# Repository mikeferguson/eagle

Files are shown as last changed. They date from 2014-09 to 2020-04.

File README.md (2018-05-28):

## Eagle CAD Stuff

This is a collection of libraries and board designs using Eagle CAD.

## Installing Eagle 7.1 (on Ubuntu 18.04)

    sudo apt-get install gcc-multilib
    sudo apt-get install libxrender1:i386 libxrandr2:i386 libxcursor1:i386 libfreetype6:i386 libfontconfig1:i386 libxi6:i386 libstdc++6:i386 libjpeg62:i386 libssl1.0.0:i386

    wget http://web.cadsoft.de/ftp/eagle/program/7.1/eagle-lin-7.1.0.run
    chmod a+x eagle-lin-7.1.0.run
    ./eagle-lin-7.1.0.run /opt

## Adding Launcher on Ubuntu 18.04
Add a file called eagle.desktop to ~/.local/share/applications:

    #!/usr/bin/env xdg-open
    [Desktop Entry]
    Comment[en_US]=Eagle 7.1
    Terminal=false
    Name[en_US]=Eagle
    Exec=/opt/eagle-7.1.0/bin/eagle
    Type=Application
    Icon=/opt/eagle-7.1.0/bin/eagleicon50.png
    StartupWMClass=dont_care

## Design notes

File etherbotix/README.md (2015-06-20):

# Etherbotix

## Notes

Notes from stuffing Rev. A:
 * DC-DC regulator is too close to Dynamixel headers (has to be installed slightly angled away)
 * X2 footprint is missing direction indicator.
 * X2 footprint should be a bit wider for hand-stuffing.
 * C39, C40 are 22pF (might still be too high)
 * Encoder capacitor values may not be right (too aggressive of a filter)

Need to source 7/16" or 11mm length, 4-40 or M3 standoff (possibly 952-1520-ND)

## Revision History

 * Rev. B - (Forthcoming)
   * Increase size of P1 indicator on X2.
   * Moved ethernet parts away from MD-03 mounting hole
   * TODO: move U3 away from AX headers
   * TODO: move J1 (ethernet jack) up a bit to avoid collision with IMU
   * TODO: update values of C39, C40
   * TODO: update values of C4, C13, C17, C18
   * TODO: move R19, R24, R25 out from under IMU
   * Move M1 encoder filter away from MD-03 mounting hole
   * Add testpads for PE0, PE1, PE4, PA8
   * Add testpads to encoders, clocks, and current sense
   * Add jumper to force bootloader
   * TODO: change away from clikmate connector
 * Rev. A - September 7, 2014
   * First release

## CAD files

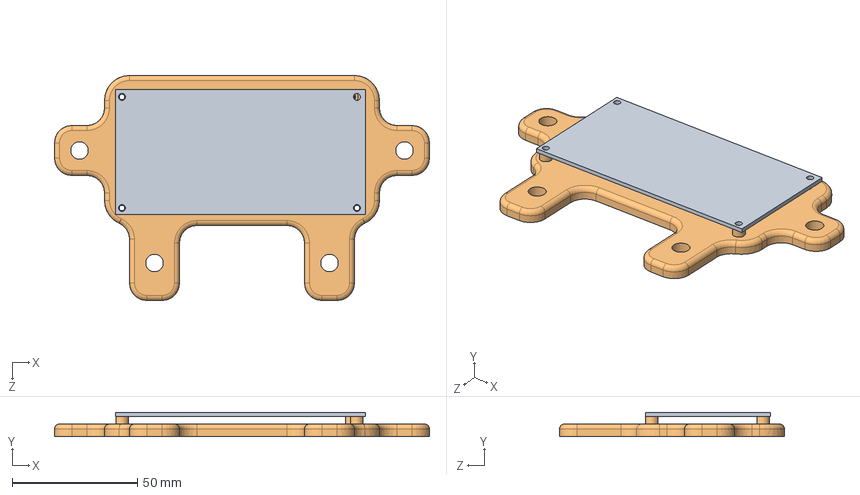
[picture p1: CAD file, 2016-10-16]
etherbotix/board-mounts/stackup.SLDASM
150.0 x 9.60 x 90.0 mm
brd-basic
mount

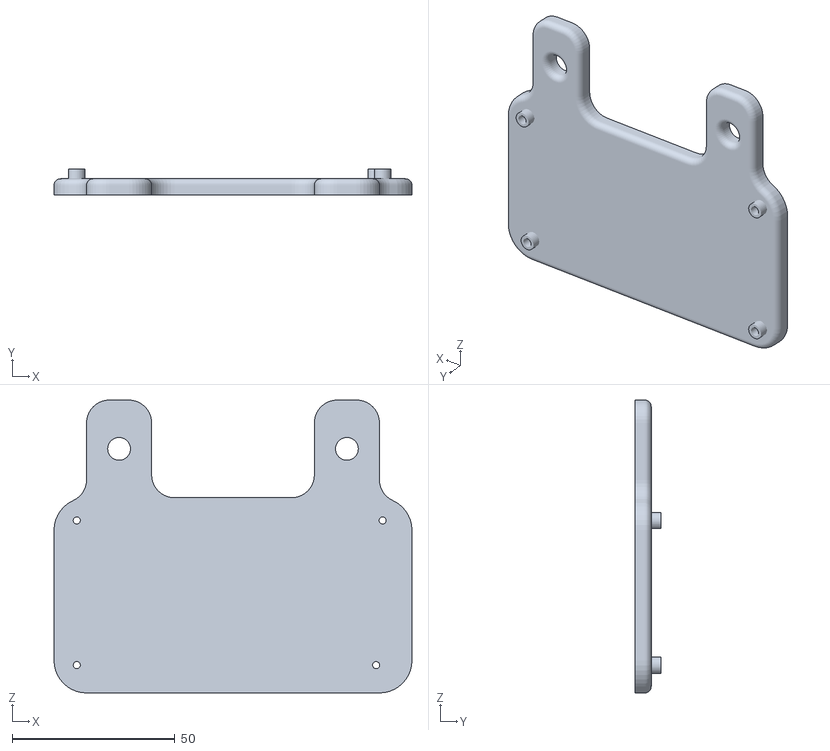
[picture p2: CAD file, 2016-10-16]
etherbotix/board-mounts/mount-teeth.STL
110.0 x 8.00 x 90.0

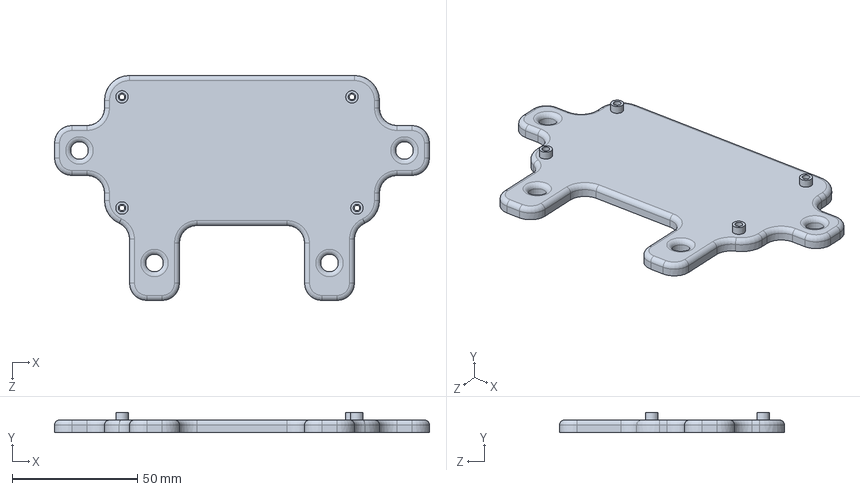
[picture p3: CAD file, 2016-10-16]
etherbotix/board-mounts/mount.SLDPRT
150.0 x 8.00 x 90.0 mm

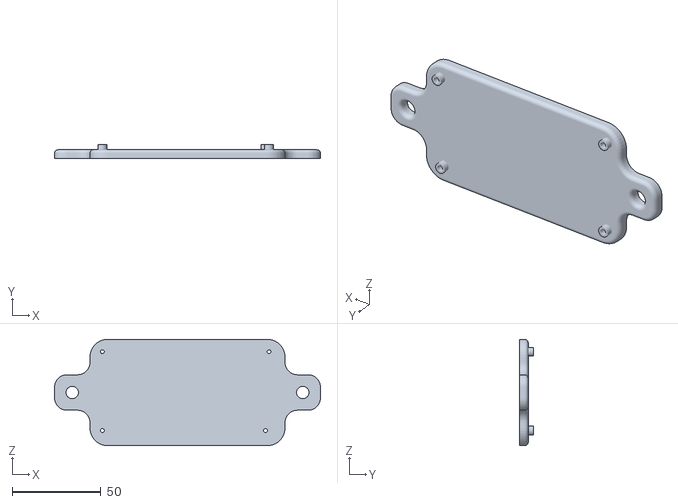
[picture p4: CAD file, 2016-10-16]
etherbotix/board-mounts/mount-end-mounts.STL
150.0 x 8.00 x 60.0

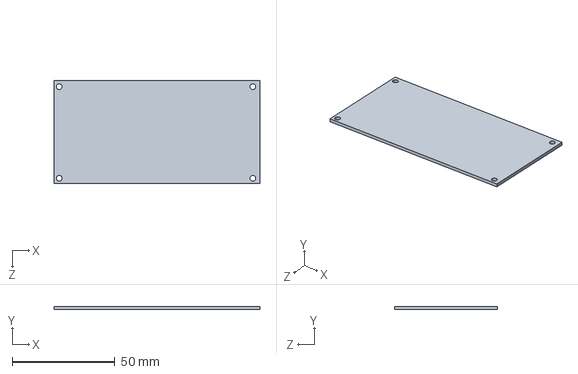
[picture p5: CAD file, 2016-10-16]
etherbotix/board-mounts/brd-basic.SLDPRT
100.0 x 1.60 x 50.0 mm

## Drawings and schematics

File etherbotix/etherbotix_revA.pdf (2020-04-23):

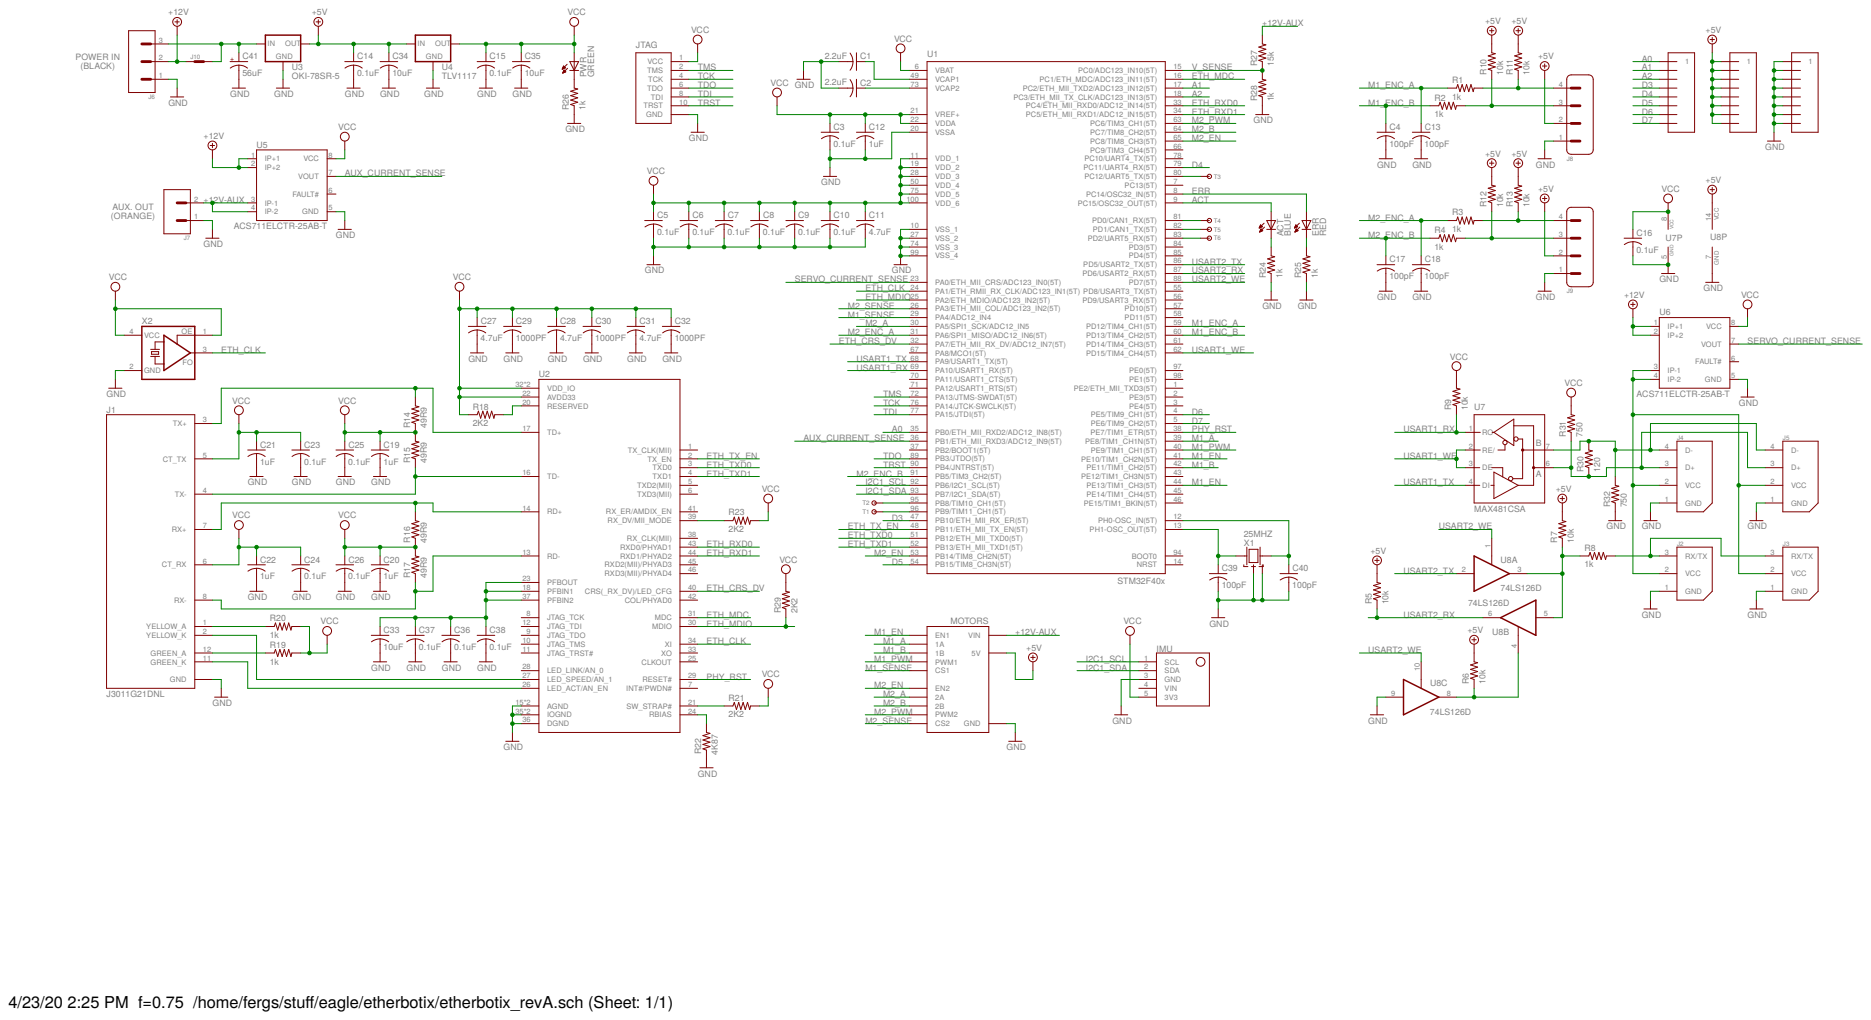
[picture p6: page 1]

100 | ACT

4/23/20 2:25 PM f=0.75 /home/fergs/stuff/eagle/etherbotix/etherbotix_revA.sch (Sheet: 1/1)

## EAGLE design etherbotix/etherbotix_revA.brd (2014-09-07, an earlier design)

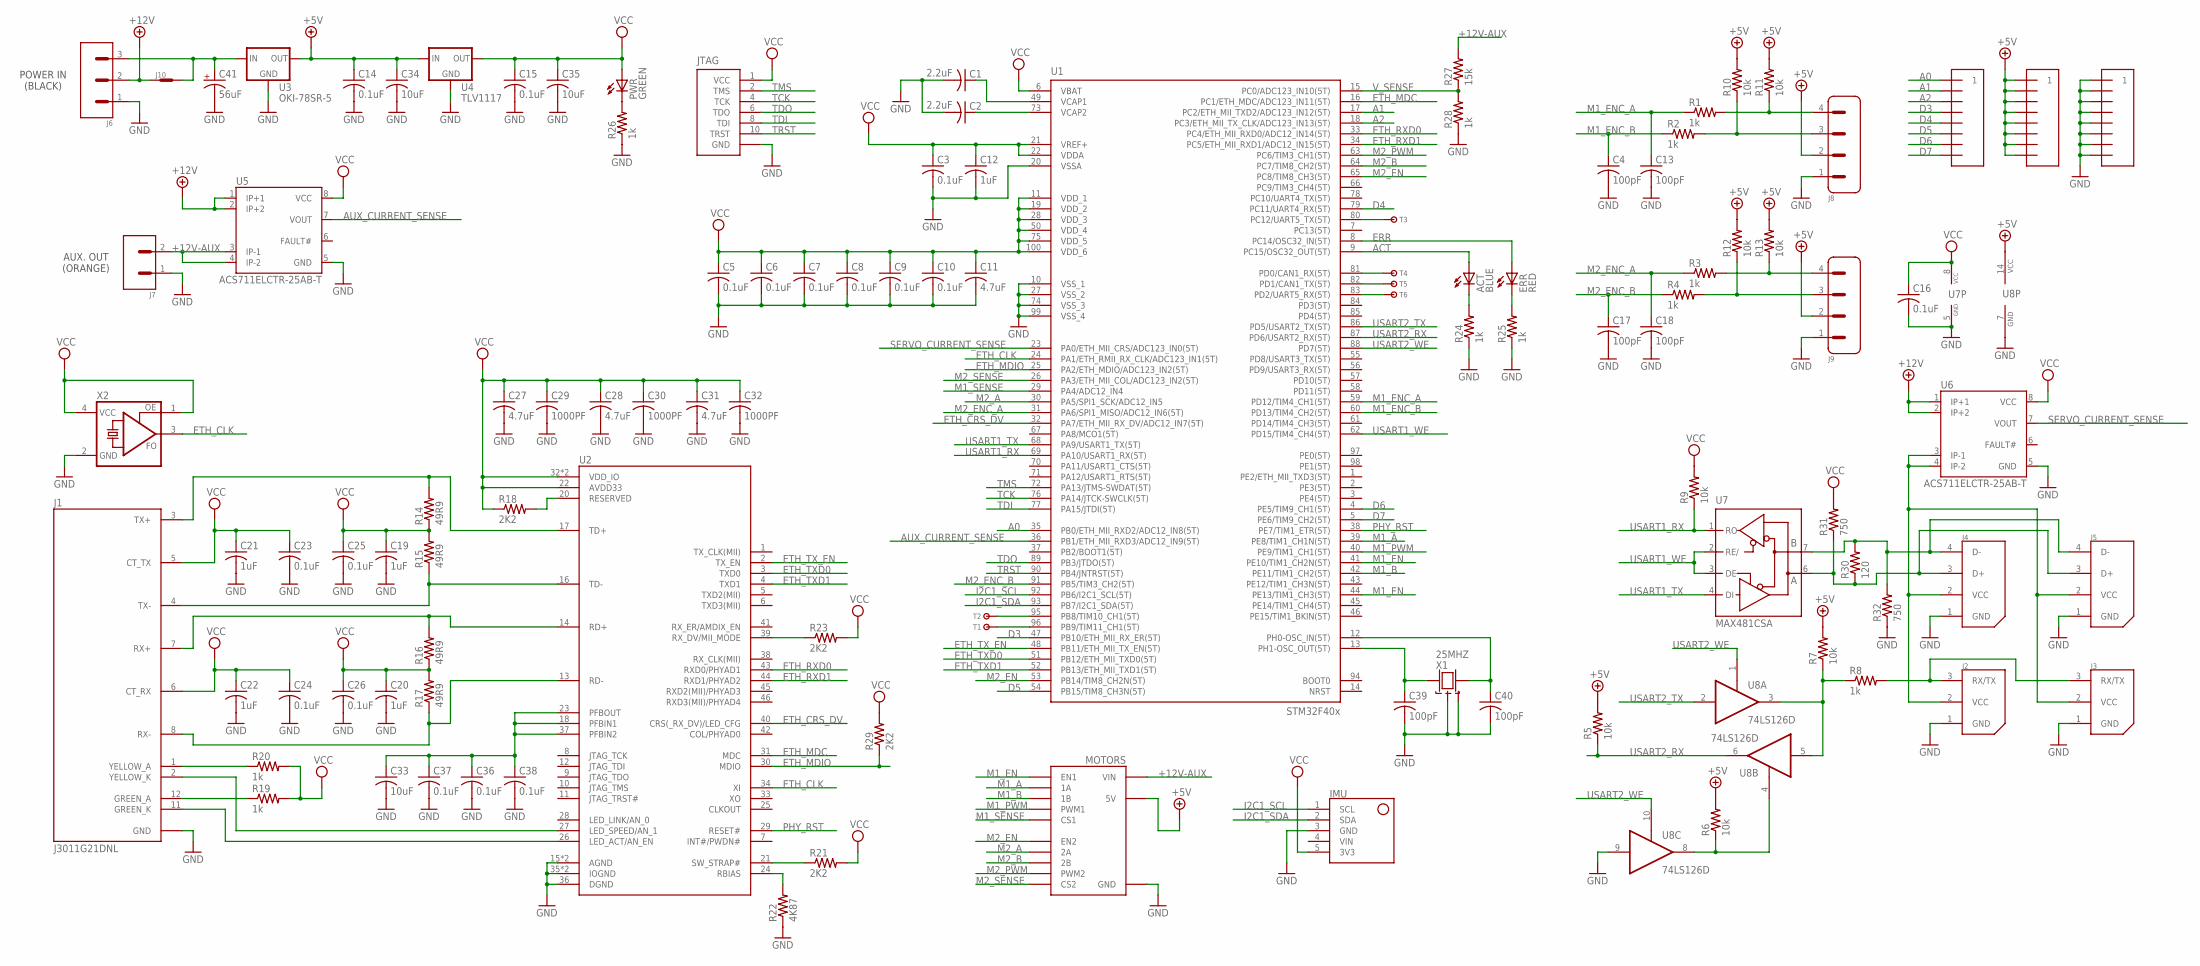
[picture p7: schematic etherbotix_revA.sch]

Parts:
ACT: BLUE; LED0603
C1, C2: 2.2uF; C0603
C3, C5, C6, C7, C8, C9, C10, C14, C15, C16, C23, C24, C25, C26, C36, C37, C38: 0.1uF; C0603
C4, C13, C17, C18, C39, C40: 100pF; C0603
C11, C27, C28, C31: 4.7uF; 0603
C12, C19, C20, C21, C22: 1uF; C0603
C29, C30, C32: 1000PF; 0603
C33, C34, C35: 10uF; C0603
C41: 56uF; OSCON_SVPF_6.3MM
ERR: RED; LED0603
IMU: MINI9IMU
J1: J3011G21DNL; J3
J2, J3: 22-03-5035; 5267-3
J4, J5: 22-03-5045; 5267-4
J6: 1760520000
J7: 1760490000
J8, J9: 502443-0470
J10: JUMPER; J2
JTAG: CORTEX_DEBUG-SHROUDED; 3220-10-0300-00
MOTORS: MD03A
PWR: GREEN; LED0603
R1, R2, R3, R4, R8, R19, R20, R24, R25, R26, R28: 1k; 0603
R5, R6, R7, R9, R10, R11, R12, R13: 10k; 0603
R14, R15, R16, R17: 49R9; 0603
R18, R21, R23, R29: 2K2; 0603
R22: 4K87; 0603
R27: 15k; 0603
R30: 120; 0603
R31, R32: 750; 0603
T1, T2, T3, T4, T5, T6: TESTPAD; TEST
U1: STM32F407V; TQFP100
U2: TLK110; LQFP48
U3: OKI-78SR-5; OKI-78SR
U4: TLV1117; DPAK
U5, U6: ACS711ELCTR-25AB-T; SOIC8
U7: MAX481CSA; SO08
U8: 74LS126D; SO14
U$1, U$2, U$3: HEADER8; 1X8
X1: 25MHZ; 4LCC
X2: ASEMB-50.000MHZ-XY-T; OSCILLATOR

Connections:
+5V: C14.1, C34.1, J8.2, J9.2, MOTORS.5V, R5.2, R6.2, R7.2, R10.2, R11.2, R12.2, R13.2, U3.P$3 (OUT), U4.3 (IN), U8.14 (VCC), U$2.P$1 (1), U$2.P$2, U$2.P$3, U$2.P$4, U$2.P$5, U$2.P$6, U$2.P$7, U$2.P$8
+12V: J6.2, J10.A, U5.1 (IP+1), U5.2 (IP+2), U6.1 (IP+1), U6.2 (IP+2)
+12V-AUX: J7.2, MOTORS.VIN1 (VIN), MOTORS.VIN2 (VIN), R27.2, U5.3 (IP-1), U5.4 (IP-2)
A0: U1.35 (PB0/ETH_MII_RXD2/ADC12_IN8(5T)), U$1.P$1 (1)
A1: U1.17 (PC2/ETH_MII_TXD2/ADC123_IN12(5T)), U$1.P$2
A2: U1.18 (PC3/ETH_MII_TX_CLK/ADC123_IN13(5T)), U$1.P$3
ACT: ACT.A, U1.9 (PC15/OSC32_OUT(5T))
AUX_CURRENT_SENSE: U1.36 (PB1/ETH_MII_RXD3/ADC12_IN9(5T)), U5.7 (VOUT)
D3: U1.47 (PB10/ETH_MII_RX_ER(5T)), U$1.P$4
D4: U1.79 (PC11/UART4_RX(5T)), U$1.P$5
D5: U1.54 (PB15/TIM8_CH3N(5T)), U$1.P$6
D6: U1.4 (PE5/TIM9_CH1(5T)), U$1.P$7
D7: U1.5 (PE6/TIM9_CH2(5T)), U$1.P$8
ERR: ERR.A, U1.8 (PC14/OSC32_IN(5T))
ETH_CLK: U1.24 (PA1/ETH_RMII_RX_CLK/ADC123_IN1(5T)), U2.34 (XI), X2.3 (FO)
ETH_CRS_DV: U1.32 (PA7/ETH_MII_RX_DV/ADC12_IN7(5T)), U2.40 (CRS(_RX_DV)/LED_CFG)
ETH_MDC: U1.16 (PC1/ETH_MDC/ADC123_IN11(5T)), U2.31 (MDC)
ETH_MDIO: R29.1, U1.25 (PA2/ETH_MDIO/ADC123_IN2(5T)), U2.30 (MDIO)
ETH_RXD0: U1.33 (PC4/ETH_MII_RXD0/ADC12_IN14(5T)), U2.43 (RXD0/PHYAD1)
ETH_RXD1: U1.34 (PC5/ETH_MII_RXD1/ADC12_IN15(5T)), U2.44 (RXD1/PHYAD2)
ETH_TXD0: U1.51 (PB12/ETH_MII_TXD0(5T)), U2.3 (TXD0)
ETH_TXD1: U1.52 (PB13/ETH_MII_TXD1(5T)), U2.4 (TXD1)
ETH_TX_EN: U1.48 (PB11/ETH_MII_TX_EN(5T)), U2.2 (TX_EN)
GND: C1.2, C2.2, C3.2, C4.2, C5.2, C6.2, C7.2, C8.2, C9.2, C10.2, C11.2, C12.2, C13.2, C14.2, C15.2, C16.2, C17.2, C18.2, C19.2, C20.2, C21.2, C22.2, C23.2, C24.2, C25.2, C26.2, C27.2, C28.2, C29.2, C30.2, C31.2, C32.2, C33.2, C34.2, C35.2, C36.2, C37.2, C38.2, C39.2, C40.2, C41.-, IMU.3 (GND), J1.9 (GND), J1.10 (GND), J1.A (GND), J1.B (GND), J2.1 (GND), J3.1 (GND), J4.1 (GND), J5.1 (GND), J6.1, J7.1, J8.1, J9.1, JTAG.3 (GND), JTAG.5 (GND), JTAG.9 (GND), MOTORS.GND1 (GND), MOTORS.GND2 (GND), R22.1, R24.1, R25.1, R26.1, R28.1, R32.1, U1.10 (VSS_1), U1.20 (VSSA), U1.27 (VSS_2), U1.74 (VSS_3), U1.99 (VSS_4), U2.15 (AGND), U2.19 (AGND), U2.35 (IOGND), U2.36 (DGND), U2.47 (IOGND), U3.P$2 (GND), U4.1 (GND), U5.5 (GND), U6.5 (GND), U7.5 (GND), U8.7 (GND), U8.9 (I), U$3.P$1 (1), U$3.P$2, U$3.P$3, U$3.P$4, U$3.P$5, U$3.P$6, U$3.P$7, U$3.P$8, X1.2 (G1), X1.4 (G2), X2.2 (GND)
I2C1_SCL: IMU.1 (SCL), U1.92 (PB6/I2C1_SCL(5T))
I2C1_SDA: IMU.2 (SDA), U1.93 (PB7/I2C1_SDA(5T))
M1_A: MOTORS.1A, U1.39 (PE8/TIM1_CH1N(5T))
M1_B: MOTORS.1B, U1.42 (PE11/TIM1_CH2(5T))
M1_EN: MOTORS.EN1, U1.41 (PE10/TIM1_CH2N(5T)), U1.44 (PE13/TIM1_CH3(5T))
M1_ENC_A: C13.1, R1.1, U1.59 (PD12/TIM4_CH1(5T))
M1_ENC_B: C4.1, R2.1, U1.60 (PD13/TIM4_CH2(5T))
M1_PWM: MOTORS.PWM1, U1.40 (PE9/TIM1_CH1(5T))
M1_SENSE: MOTORS.CS1, U1.29 (PA4/ADC12_IN4)
M2_A: MOTORS.2A, U1.30 (PA5/SPI1_SCK/ADC12_IN5)
M2_B: MOTORS.2B, U1.64 (PC7/TIM8_CH2(5T))
M2_EN: MOTORS.EN2, U1.53 (PB14/TIM8_CH2N(5T)), U1.65 (PC8/TIM8_CH3(5T))
M2_ENC_A: C18.1, R3.1, U1.31 (PA6/SPI1_MISO/ADC12_IN6(5T))
M2_ENC_B: C17.1, R4.1, U1.91 (PB5/TIM3_CH2(5T))
M2_PWM: MOTORS.PWM2, U1.63 (PC6/TIM3_CH1(5T))
M2_SENSE: MOTORS.CS2, U1.26 (PA3/ETH_MII_COL/ADC123_IN2(5T))
unnamed: J1.4 (TX-), R15.1, U2.16 (TD-)
unnamed: J2.2 (VCC), J3.2 (VCC), J4.2 (VCC), J5.2 (VCC), U6.3 (IP-1), U6.4 (IP-2)
unnamed: C39.1, U1.13 (PH1-OSC_OUT(5T)), X1.1
unnamed: C1.1, U1.49 (VCAP1)
unnamed: C2.1, U1.73 (VCAP2)
unnamed: J8.3, R2.2, R10.1
unnamed: J8.4, R1.2, R11.1
unnamed: J9.4, R3.2, R13.1
unnamed: J9.3, R4.2, R12.1
unnamed: J4.3 (D+), J5.3 (D+), R30.1, R31.1, U7.6 (A)
unnamed: J4.4 (D-), J5.4 (D-), R30.2, R32.2, U7.7 (B)
unnamed: R7.1, R8.1, U8.3 (O), U8.5 (I)
unnamed: R6.1, U8.4 (OE), U8.8 (O)
unnamed: J2.3 (RX/TX), J3.3 (RX/TX), R8.2
unnamed: C40.1, U1.12 (PH0-OSC_IN(5T)), X1.3
unnamed: J1.3 (TX+), R14.2, U2.17 (TD+)
unnamed: R18.2, U2.20 (RESERVED)
unnamed: J1.2 (YELLOW_K), U2.27 (LED_SPEED/AN_1)
unnamed: J1.7 (RX+), R16.2, U2.14 (RD+)
unnamed: J1.11 (GREEN_K), U2.26 (LED_ACT/AN_EN)
unnamed: J1.8 (RX-), R17.1, U2.13 (RD-)
unnamed: J1.1 (YELLOW_A), R20.1
unnamed: J1.12 (GREEN_A), R19.1
unnamed: C33.1, C36.1, C37.1, C38.1, U2.18 (PFBIN1), U2.23 (PFBOUT), U2.37 (PFBIN2)
unnamed: R21.1, U2.21 (SW_STRAP#)
unnamed: R22.2, U2.24 (RBIAS)
unnamed: R23.1, U2.39 (RX_DV/MII_MODE)
unnamed: PWR.C, R26.2
unnamed: C41.+, J6.3, J10.B, U3.P$1 (IN)
unnamed: ERR.C, R25.2
unnamed: ACT.C, R24.2
PB8: T2.T, U1.95 (PB8/TIM10_CH1(5T))
PB9: T1.T, U1.96 (PB9/TIM11_CH1(5T))
PC12: T3.T, U1.80 (PC12/UART5_TX(5T))
PD0: T4.T, U1.81 (PD0/CAN1_RX(5T))
PD1: T5.T, U1.82 (PD1/CAN1_TX(5T))
PD2: T6.T, U1.83 (PD2/UART5_RX(5T))
PHY_RST: U1.38 (PE7/TIM1_ETR(5T)), U2.29 (RESET#)
SERVO_CURRENT_SENSE: U1.23 (PA0/ETH_MII_CRS/ADC123_IN0(5T)), U6.7 (VOUT)
TCK: JTAG.4 (TCK), U1.76 (PA14/JTCK-SWCLK(5T))
TDI: JTAG.8 (TDI), U1.77 (PA15/JTDI(5T))
TDO: JTAG.6 (TDO), U1.89 (PB3/JTDO(5T))
TMS: JTAG.2 (TMS), U1.72 (PA13/JTMS-SWDAT(5T))
TRST: JTAG.10 (TRST), U1.90 (PB4/JNTRST(5T))
USART1_RX: R9.1, U1.69 (PA10/USART1_RX(5T)), U7.1 (RO)
USART1_TX: U1.68 (PA9/USART1_TX(5T)), U7.4 (DI)
USART1_WE: U1.62 (PD15/TIM4_CH4(5T)), U7.2 (RE/), U7.3 (DE)
USART2_RX: R5.1, U1.87 (PD6/USART2_RX(5T)), U8.6 (O)
USART2_TX: U1.86 (PD5/USART2_TX(5T)), U8.2 (I)
USART2_WE: U1.88 (PD7(5T)), U8.1 (OE), U8.10 (OE)
VCC: C3.1, C5.1, C6.1, C7.1, C8.1, C9.1, C10.1, C11.1, C12.1, C15.1, C16.1, C19.1, C20.1, C21.1, C22.1, C23.1, C24.1, C25.1, C26.1, C27.1, C28.1, C29.1, C30.1, C31.1, C32.1, C35.1, IMU.5 (3V3), J1.5 (CT_TX), J1.6 (CT_RX), JTAG.1 (VCC), PWR.A, R9.2, R14.1, R15.2, R16.1, R17.2, R18.1, R19.2, R20.2, R21.2, R23.2, R29.2, R31.2, U1.6 (VBAT), U1.11 (VDD_1), U1.19 (VDD_2), U1.21 (VREF+), U1.22 (VDDA), U1.28 (VDD_3), U1.50 (VDD_4), U1.75 (VDD_5), U1.100 (VDD_6), U2.22 (AVDD33), U2.32 (VDD_IO), U2.48 (VDD_IO), U4.4 (OUT), U5.8 (VCC), U6.8 (VCC), U7.8 (VCC), X2.1 (OE), X2.4 (VCC)
V_SENSE: R27.1, R28.2, U1.15 (PC0/ADC123_IN10(5T))

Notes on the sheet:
POWER IN (BLACK)
AUX. OUT (ORANGE)

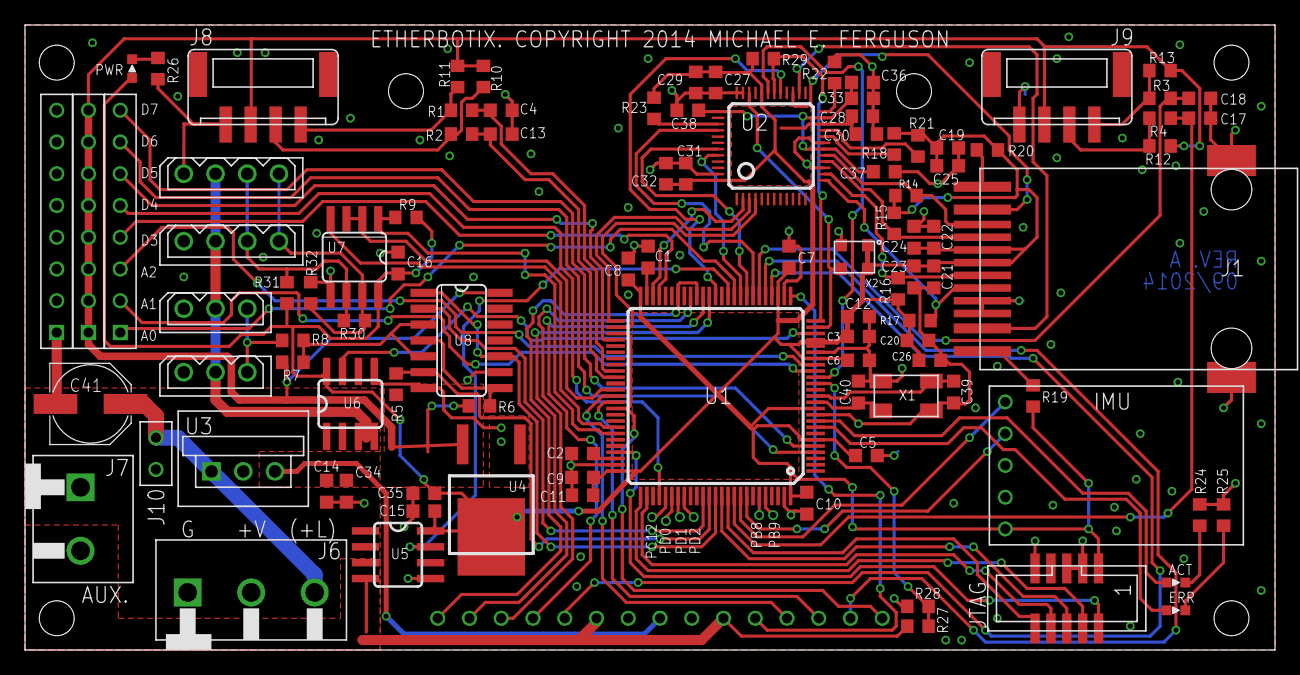
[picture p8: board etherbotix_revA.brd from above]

Board: 2 copper layers, 100.0 x 50.0 mm, 108 parts (0 on the bottom side), 92 nets.

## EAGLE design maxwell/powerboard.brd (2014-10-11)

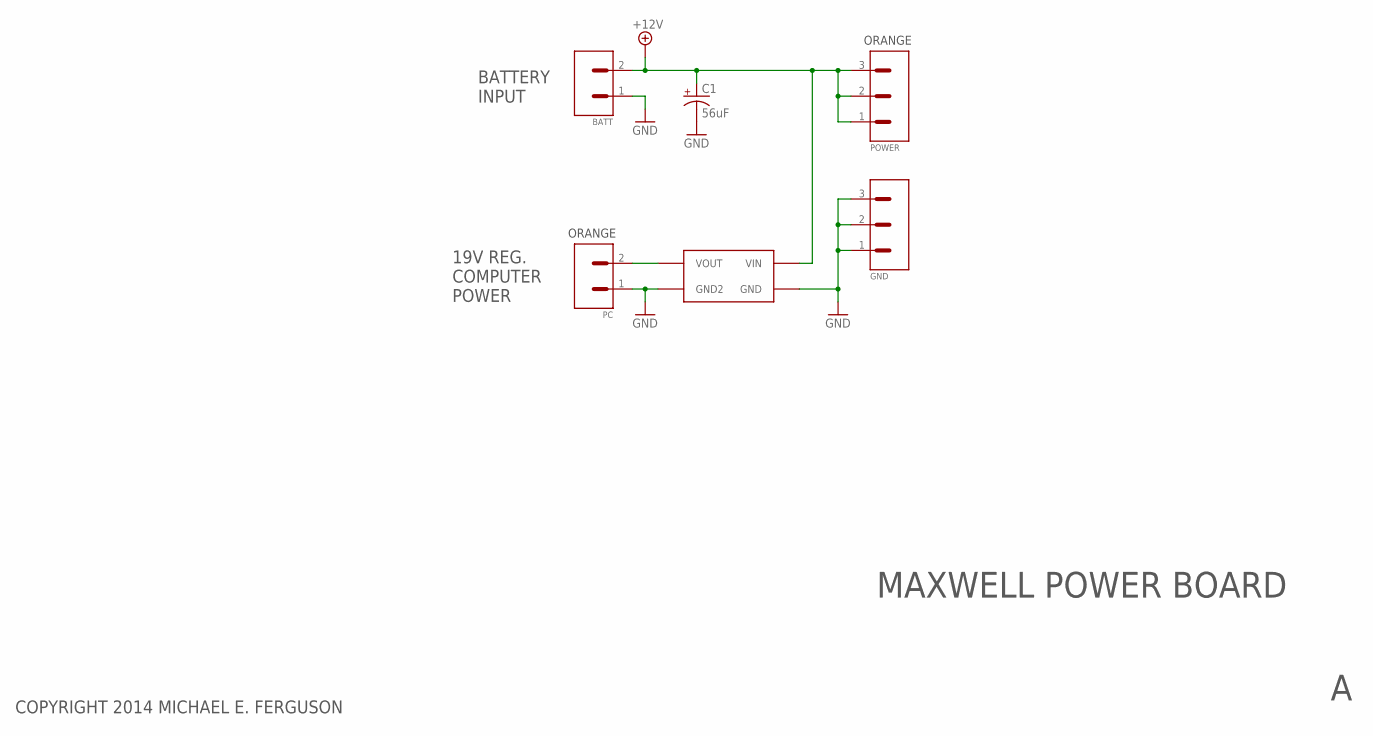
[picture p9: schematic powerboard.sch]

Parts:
BATT: 1760510000; 1760490000
C1: 56uF; OSCON_SVPF_6.3MM
GND: 1760520000
PC: 1760490000
POWER: 1760520000
U3V50AVH: U3V50AHV

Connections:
+12V: BATT.2, C1.+, POWER.1, POWER.2, POWER.3, U3V50AVH.V_IN (VIN)
GND: BATT.1, C1.-, GND.1, GND.2, GND.3, PC.1, U3V50AVH.GND_IN (GND), U3V50AVH.GND_OUT (GND2)
unnamed: PC.2, U3V50AVH.V_OUT (VOUT)

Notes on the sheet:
BATTERY INPUT
19V REG. COMPUTER POWER
ORANGE
MAXWELL POWER BOARD
COPYRIGHT 2014 MICHAEL E. FERGUSON

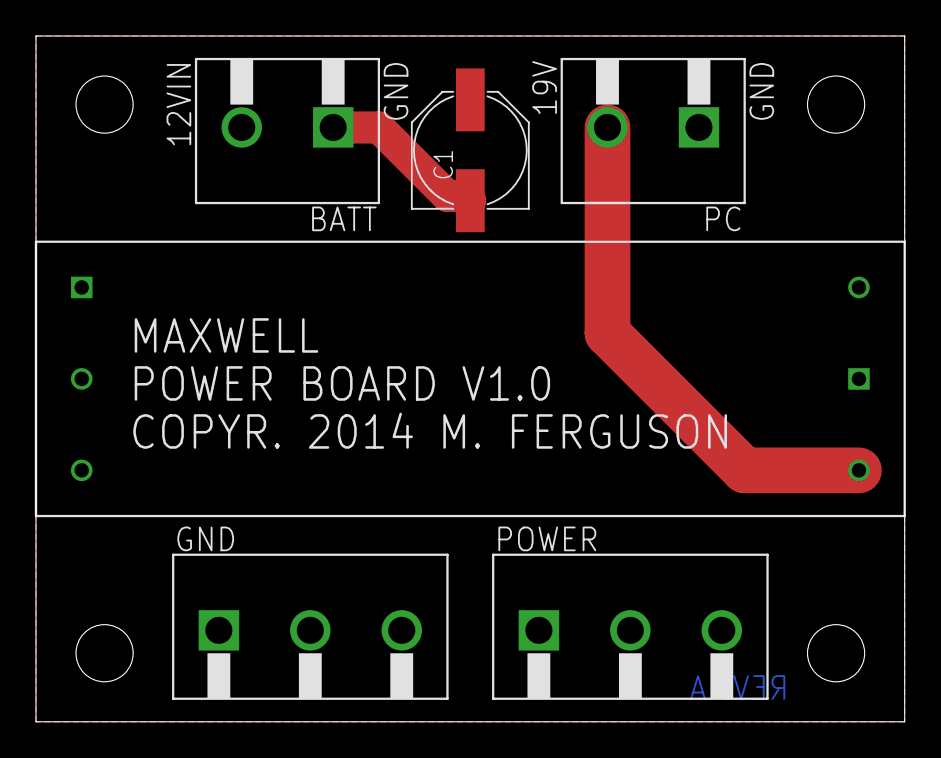
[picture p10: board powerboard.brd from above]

Board: 2 copper layers, 48.3 x 38.1 mm, 6 parts (0 on the bottom side), 3 nets.

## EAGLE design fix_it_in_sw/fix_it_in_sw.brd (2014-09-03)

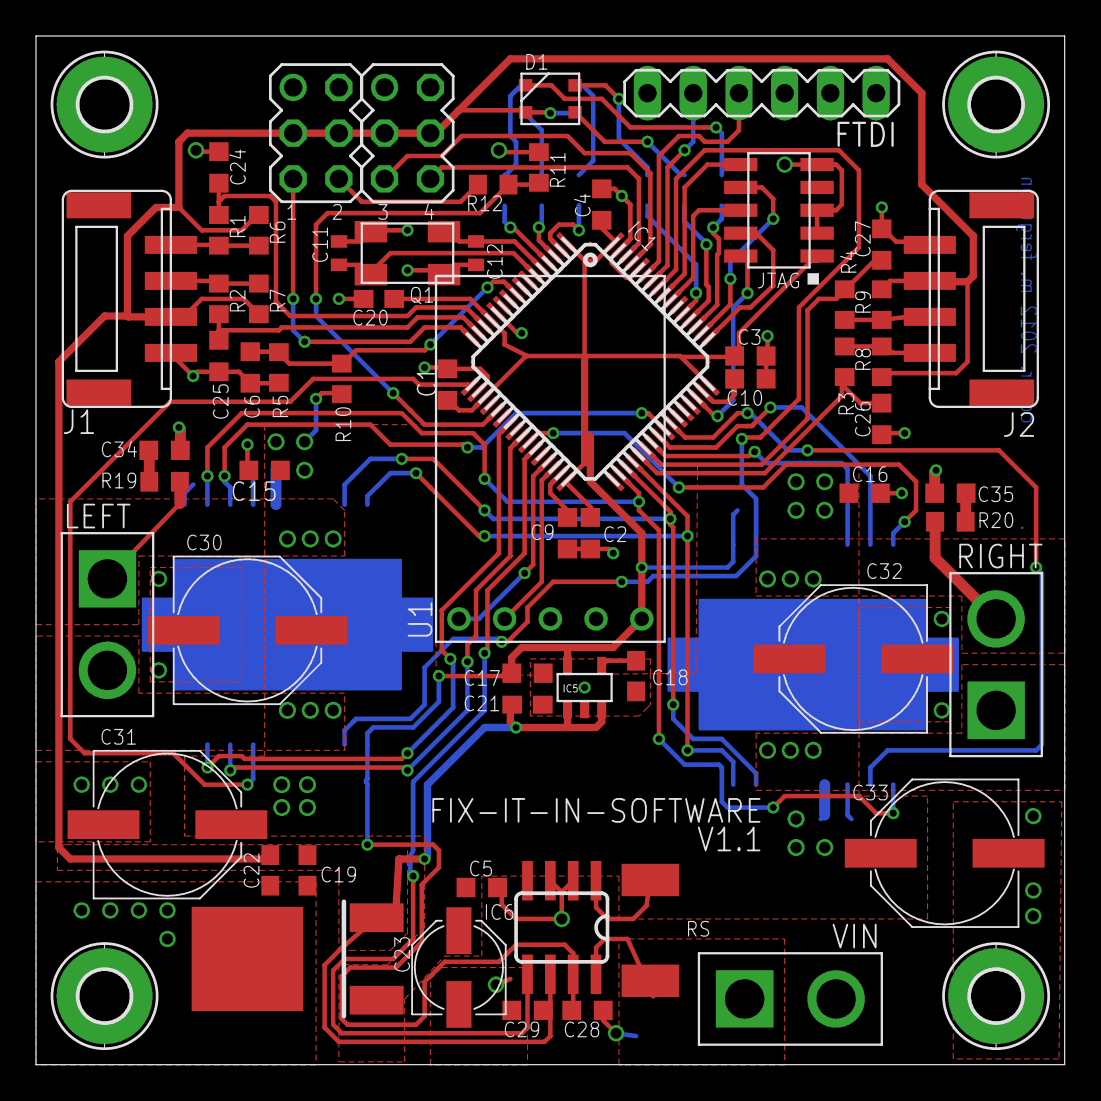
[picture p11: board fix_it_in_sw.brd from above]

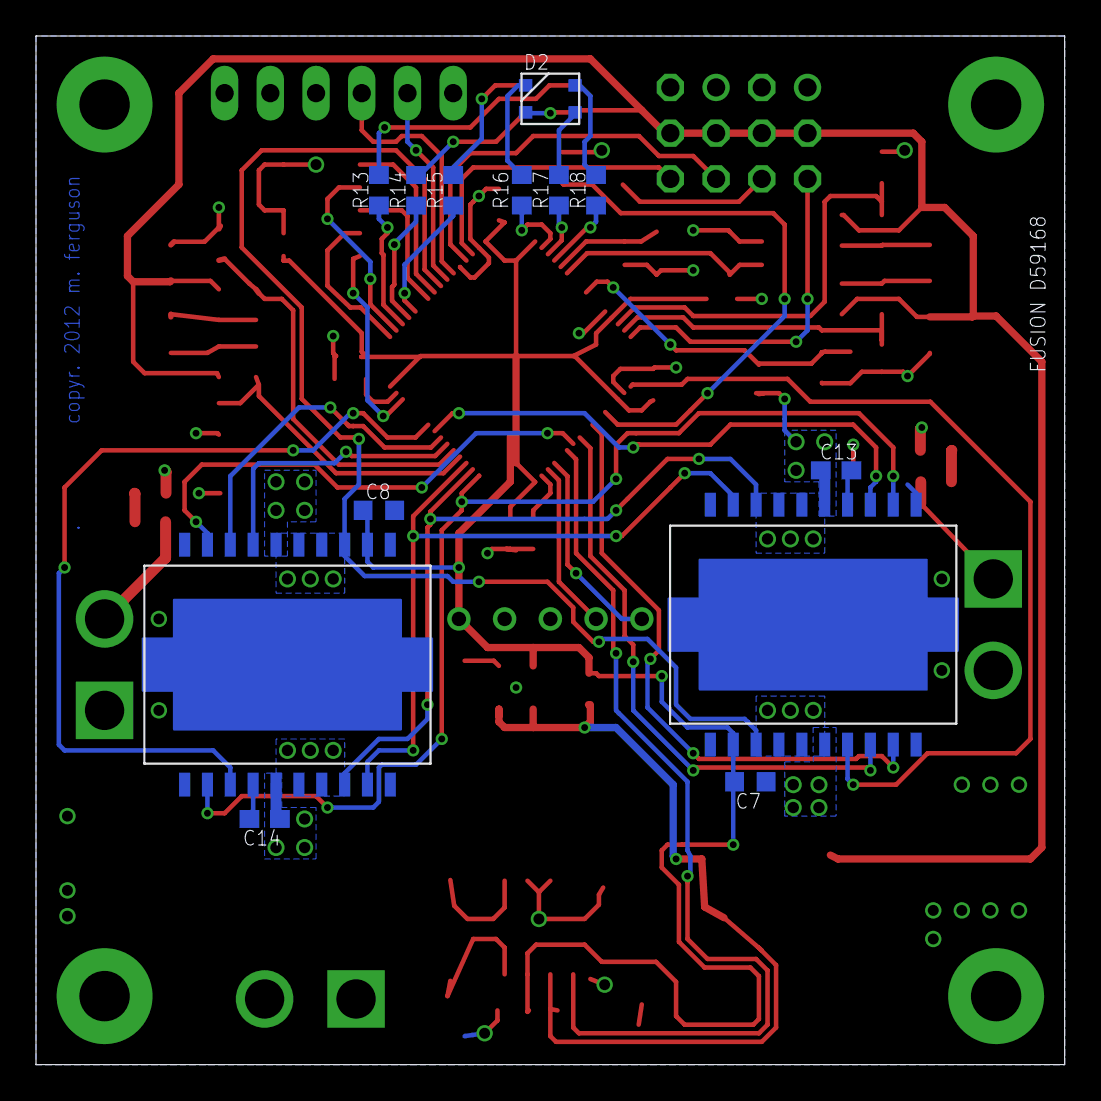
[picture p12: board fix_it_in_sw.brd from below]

Board: 2 copper layers, 57.1 x 57.1 mm, 79 parts (13 on the bottom side), 66 nets.

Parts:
C1, C2, C3, C4, C5, C6, C7, C8, C15, C16, C28, C29: 0.1uF; C0603
C9, C10, C17: 2.2uF; C0603
C11, C12: 33pF; C0402
C13, C14: 22000pF; C0603
C18: 470pF; C0603
C19, C20, C21: 1uF; C0603
C22: 10uF; C0603
C23: 33uF; PANASONIC_C
C24, C25, C26, C27: 100pF; C0603
C30, C31, C32, C33: 100uF; PANASONIC_F
C34, C35: C0603
D1, D2: CREE-PLCC-4
FTDI: MA06-1
H1, H2, H3, H4: MOUNT-PAD-ROUND2.8; 2,8-PAD
IC1: STM32F405RG; TQFP64
IC2, IC3: NCV7729BPPR2G; PSOP-20
IC4: NCP5501DT50RKG; DPAK
IC5: TPS79933DDCR; SOT-23-5
IC6: AD8205R; SO8
J1, J2: 502443-0470
JTAG: GRPB052VWQS-RC; DEBUG
LEFT: POWER
Q1: 8MHZ; 4LCC
R1, R2, R3, R4, R5, R13, R14, R15, R16, R17, R18: 1k; R0603
R6, R7, R8, R9, R10, R11: 2k49; R0603
R12: 1k5; R0603
R19, R20: R0603
RIGHT: POWER
RS: R2512
SV1, SV2: MA03-2
U1: MINI9IMU
VIN: POWER

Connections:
+5V: C19.1, C21.1, C22.1, C29.1, D1.2, D2.2, IC4.3, IC5.1, IC5.3, IC6.6, J1.2, J2.2, R6.2, R7.2, R8.2, R9.2, SV1.3, SV1.4, SV2.3, SV2.4
+7V: C5.1, C13.1, C14.1, C15.1, C16.1, C23.+, C30.+, C31.+, C32.+, C33.+, IC2.5, IC2.16, IC3.5, IC3.16, IC4.1, IC6.1, R10.2, RS.2
BOT_B: IC1.4, R18.2
BOT_G: IC1.3, R17.2
BOT_R: IC1.2, R16.2
CH1: IC1.16, SV1.5
CH2: IC1.21, R11.2, R12.1
CH3: IC1.61, SV2.5
CH4: IC1.62, SV2.6
CURRENT_SENSE: IC1.27, IC6.5
GND: C1.2, C2.2, C3.2, C4.2, C5.2, C6.2, C7.2, C8.2, C9.2, C10.2, C11.2, C12.2, C15.2, C16.2, C17.2, C18.2, C19.2, C20.2, C21.2, C22.2, C23.-, C24.2, C25.2, C26.2, C27.2, C28.2, C29.2, C30.-, C31.-, C32.-, C33.-, C34.2, C35.2, FTDI.1, FTDI.2, IC1.12, IC1.18, IC1.60, IC1.63, IC2.1, IC2.10, IC2.11, IC2.20, IC2.THERMAL, IC3.1, IC3.10, IC3.11, IC3.20, IC3.THERMAL, IC4.4, IC5.2, IC6.2, IC6.3, J1.1, J2.1, JTAG.3, JTAG.5, JTAG.9, Q1.2, Q1.4, R5.1, R11.1, SV1.1, SV1.2, SV2.1, SV2.2, U1.3, VIN.-
L+: IC2.6, IC2.7, LEFT.+, R19.2
L-: IC2.14, IC2.15, LEFT.-
LEFT_CS: IC1.17, IC2.17
LEFT_ENC_A: C24.1, IC1.14, R1.2
LEFT_ENC_B: C25.1, IC1.15, R2.2
L_FAULT: IC1.25, IC2.18
MISO: IC1.35, IC2.8, IC3.8
MOSI: IC1.36, IC2.9, IC3.9
M_EN: IC1.57, IC2.13, IC3.13
unnamed: R12.2, SV1.6
unnamed: C11.1, IC1.6, Q1.1
unnamed: J1.4, R1.1, R6.1
unnamed: C12.1, IC1.5, Q1.3
unnamed: J1.3, R2.1, R7.1
unnamed: C9.1, IC1.31
unnamed: C34.1, R19.1
unnamed: C35.1, R20.1
unnamed: C13.2, IC2.4
unnamed: J2.4, R3.1, R8.1
unnamed: C10.1, IC1.47
unnamed: C14.2, IC3.4
unnamed: C18.1, IC5.4
unnamed: D2.4, R18.1
unnamed: J2.3, R4.1, R9.1
unnamed: D2.3, R17.1
unnamed: D2.1, R16.1
unnamed: D1.1, R13.1
unnamed: D1.3, R14.1
unnamed: D1.4, R15.1
R+: IC3.6, IC3.7, RIGHT.+
R-: IC3.14, IC3.15, R20.2, RIGHT.-
RIGHT_CS: IC1.39, IC3.17
RIGHT_ENC_A: C26.1, IC1.37, R3.2
RIGHT_ENC_B: C27.1, IC1.38, R4.2
RX: FTDI.4, IC1.59
R_FAULT: IC1.40, IC3.18
SCK: IC1.34, IC2.2, IC3.2
SCL: IC1.29, U1.1
SDA: IC1.30, U1.2
TCK: IC1.49, JTAG.4
TDI: IC1.50, JTAG.8
TDO: IC1.55, JTAG.6
TIM1_CH1: IC1.41, IC2.3
TIM1_CH1N: IC1.23, IC2.19
TIM1_CH2: IC1.42, IC3.3
TIM1_CH2N: IC1.26, IC3.19
TMS: IC1.46, JTAG.2
TOP_B: IC1.53, R15.2
TOP_G: IC1.52, R14.2
TOP_R: IC1.51, R13.2
TRST: IC1.56, JTAG.10
TX: FTDI.5, IC1.58
VCC: C1.1, C2.1, C3.1, C4.1, C7.1, C8.1, C17.1, C20.1, C28.1, IC1.1, IC1.13, IC1.19, IC1.32, IC1.48, IC1.64, IC2.12, IC3.12, IC5.5, IC6.7, JTAG.1, U1.5
VIN: IC6.8, RS.1, VIN.+
VOLTAGE_SENSE: C6.1, IC1.9, R5.2, R10.1

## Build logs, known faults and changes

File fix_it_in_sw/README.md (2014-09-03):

# Fix-it-in-software
This board was a simple STM32F4 board using the 64-lqfp part. It was
designed for a battle bot that was never built. It includes:

 * 2 medium-current motor drivers
 * 2 encoder inputs
 * Header for Pololu Mini-IMU v2
 * Bidirectional current sense
 * Headers connected to appropriate timers for RC inputs

The software was never really finished.

This design was done in Eagle 5.x and imported to Eagle 7.1 -- it has
not been tested (there may be issues with the import)

This board is sized to work with SeeedStudio's 5cm X 5cm size limit.

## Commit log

2014-09-03 add fix_it_in_sw
    [fix_it_in_sw.brd, fix_it_in_sw.sch]
2014-09-03 add stm library from stm32 repo
2014-09-03 import pololu library with IMU
2014-09-03 add power library
2014-09-03 check in start of new etherbotix board
    [etherbotix.brd, etherbotix.sch]
2014-09-05 remove extra silkscreen from MD03
2014-09-05 routed, still needs cleanup
    [etherbotix.brd, etherbotix.sch]
2014-09-05 add some more resistors/caps
2014-09-05 adjust ethernet parts for easier schematic routing
2014-09-05 pass DRC
    [etherbotix.brd]
2014-09-05 fix part number of 1760510000
    [etherbotix.brd, etherbotix.sch]
2014-09-05 add testpads
    [etherbotix.brd, etherbotix.sch]
2014-09-05 add notes to silkscreen
    [etherbotix.brd]
2014-09-05 minor tweaks to silkscreen
    [etherbotix.brd]
2014-09-05 check in gerber generation config for seeed
2014-09-06 fix sizing of MD03
    [etherbotix.brd, etherbotix.sch]
2014-09-06 move imu slightly down
    [etherbotix.brd]
2014-09-06 some more refinements
    [etherbotix.brd]
2014-09-07 add estop-capable 3-pin VIN header
    [etherbotix.brd, etherbotix.sch]
2014-09-07 add top-side ground plane
    [etherbotix.brd]
2014-09-07 switch MD03A outline to tDocu
2014-09-07 update footprint of TLV1117
2014-09-07 nearly done with layout
    [etherbotix.brd, etherbotix.sch]
2014-09-07 final rev. A updates
    [etherbotix.brd, etherbotix.sch]
2014-09-07 upload gerber package for rev. A
2014-09-20 add notes on MD03 standoff
2014-09-22 start rev. B
    [etherbotix.brd, etherbotix.sch]
2014-09-22 add testpads to clocks, encoders, current sense
    [etherbotix.brd, etherbotix.sch]
2014-09-22 add testpad for PA8 (mco1)
    [etherbotix.brd, etherbotix.sch]
2014-10-11 add new powerboard for maxwell
    [powerboard.brd, powerboard.sch]
2014-10-15 add pololu motor driver and step up regulator
2014-10-15 add maxwell schematic, some schematic elements
    [maxwell.sch]
2014-10-19 add pin to force staying in bootloader
    [etherbotix.brd, etherbotix.sch]
2015-02-12 Adding board mount files. Including two configurations.
    [brd-basic.SLDPRT, mount-end-mounts.STL, mount-teeth.STL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]
2015-02-12 Adding filets to screw holes.
    [mount-end-mounts.STL, mount-teeth.STL, mount.SLDPRT]
2015-06-20 increase size of pin 1 indicator on X2
    [etherbotix.brd, etherbotix.sch]
2015-06-20 move parts away from MD-03 hole
    [etherbotix.brd]
2018-04-03 reorganize so both revisions of etherbotix are visible
    [etherbotix_revA.brd, etherbotix_revA.sch, etherbotix_revB.brd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]
2018-04-05 fix motor wires that were reversed
    [maxwell.sch]
2018-04-24 reorder pins, cleans up schematic
2018-04-24 add FPC, smaller clik-mate connectors
2018-04-24 add CUI power regulators
2018-04-24 add current sense resistor
2018-05-01 update qfp64 package, move pin drawing to tdoc layer
2018-05-15 add parts, fix pin order of VC78-1000
2018-08-28 fix orientation of FFC for maxon motors
2018-09-03 add a number of molex connectors
2020-04-23 add PDF of schematic

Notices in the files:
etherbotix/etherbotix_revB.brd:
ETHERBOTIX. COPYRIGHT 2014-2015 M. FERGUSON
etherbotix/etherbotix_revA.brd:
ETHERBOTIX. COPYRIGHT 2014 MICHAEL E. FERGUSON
